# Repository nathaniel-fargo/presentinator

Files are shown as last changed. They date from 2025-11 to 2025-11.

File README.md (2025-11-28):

# the PRESENTINATOR

## Plot
Santa got a cold, and it's December 24th! As his top elf you gotta step it up\
You decide to make a cannon to launch presents from the North Pole all over the world.\
Each house will light up when it's clock strikes midnight and you must shoot your target to the correct one.\
The longer you hold the trigger, the further your present will be shot. You call it, "the PRESENTINATOR".\
(Depending on how well this goes, you might be in for a raise aftewards... and boy do you love Candy Canes)

## Project
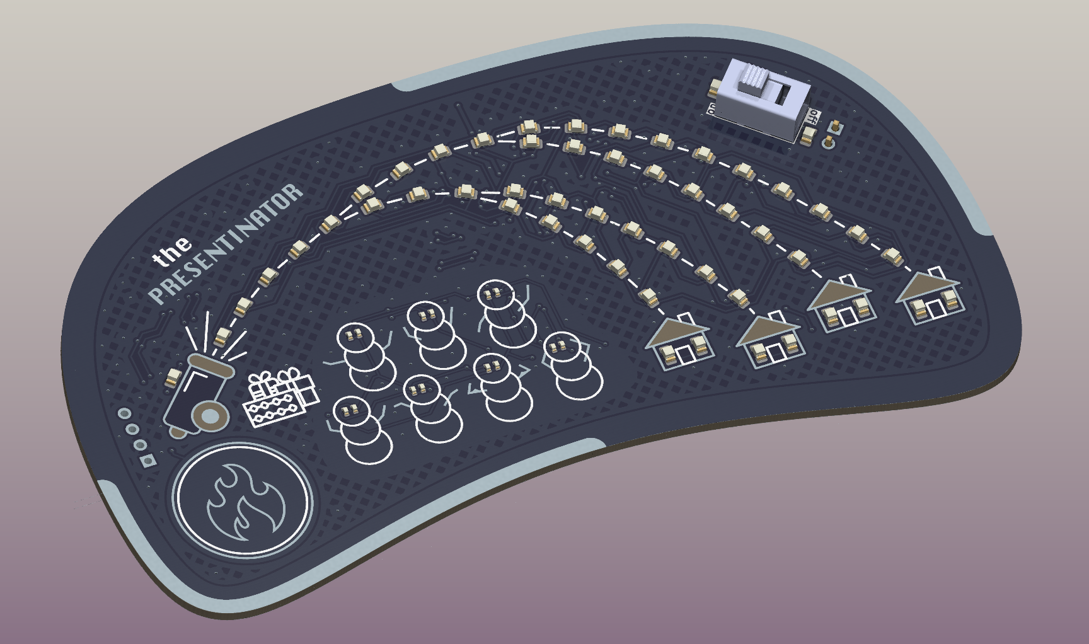
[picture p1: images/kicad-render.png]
KiCad PCB Render

There's hardware, graphics, and soon to be firmware in this repo.\
I initially designed this as a four layer board, but when I experimenting with deleting the inner layers, practically all the grounds were routed together besides a few floating islands. Everything should be low speed enough so that's fine.\
The project is powered off of two 2032s, with a switch, and then minimal polarity protection and then bucked down to 3.3V.\
The brains of the operation is the STM32F030F4, a very minimal STM microcontroller.\
Over I2C it drives the IS31FL3731-SA LED Matrix driver, which is not used to full capacity.\
There's also a capactive sense button IC, as well as the capability to drive a vibration motor for full haptic I/O.

## Status
Hardware: Designed\
Board: Being manufactured\
Firmware: Will be done by Christmas

## License
MIT Open Source License-inator

## Motivation
I have some younger people in my life and a habit of making DIY christmas presents. In the past they've been largely "crafty" (e.g. wood, leather) but this year I went all-in on electronics.

## Inspiration
Roughly inspired by the [light rail](https://github.com/nonik0/Light-Rail) PCB train track project, as well as Doofenshmirtz's naming conventions.

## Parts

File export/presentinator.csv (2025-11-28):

Reference | Qty | Value | Footprint | DK_PN | Stocked
BT1 | 1 | CR2032 | Aloe:BAT_BAT-HLD-003-SMT | 1908-CR2032-ND
BT2 | 1 | CR2032 | Aloe:BAT_BAT-HLD-003-SMT | 343-BAT-HLD-003-SMT-ND
C1,C2,C3,C4,C5,C6,C7 | 7 | 4u7 | Capacitor_SMD:C_0402_1005Metric_Pad0.74x0.62mm_HandSolder |  | y
CB1 | 1 | Touch Me | TestPoint:TestPoint_Pad_1.0x1.0mm |  | y
D25 | 1 | RB521S30T1G | Diode_SMD:D_SOD-523 |  | y
DB1 | 1 | LED | LED_SMD:LED_0805_2012Metric_InnerMarking | B1701NB--20D000114U1930
DB2 | 1 | LED | LED_SMD:LED_0805_2012Metric_InnerMarking | B1701URO-20D000114U1930
DC1,DH2,DH4,DH6,DH8 | 5 | LED_Small | LED_SMD:LED_0805_2012Metric_InnerMarking | B1701URO-20D000114U1930
DH1,DH3,DH5,DH7 | 4 | LED_Small | LED_SMD:LED_0805_2012Metric_InnerMarking | B1701NB--20D000114U1930
DP1,DP2,DP3,DP4,DP5,DP6,DP7,DP8,DP9,DP10,DP11,DP12,DP13,DP14,DP15,DP16,DP17,DP18,DP19,DP20,DP21,DP22,DP23,DP24,DP25,DP26,DP27,DP28,DP29,DP30,DP31,DP32,DP33,DP34,DP35,DP36,DP37,DP38,DP39,DP40,DP41,DP42 | 42 | LED_Small | LED_SMD:LED_0805_2012Metric_InnerMarking | B1701UY--20D000214U1930
DS1,DS2,DS3,DS4,DS5,DS6,DS7,DS8,DS9,DS10,DS11,DS12,DS13,DS14 | 14 | LED_Small | LED_SMD:LED_0402_1005Metric_Minimal | EAST10052WA0
J1 | 1 | SWD | Connector_PinHeader_2.54mm:PinHeader_1x04_P2.54mm_Vertical |  | y
L1 | 1 | MAMK2520T4R7M | Inductor_SMD:L_1008_2520Metric_Pad1.43x2.20mm_HandSolder | MAMK2520T4R7M
M1 | 1 | Motor_DC | Connector_PinHeader_2.54mm:PinHeader_1x02_P2.54mm_Vertical | 1188-VIBRATING-MOTOR-ND
Q1 | 1 | PJA3401A | Package_TO_SOT_SMD:SOT-23-3 | PJA3401A_R1_00001
Q2 | 1 | AO3400A | Package_TO_SOT_SMD:SOT-23-3 | AO3400A
R1 | 1 | 100 | Resistor_SMD:R_0402_1005Metric_Pad0.72x0.64mm_HandSolder |  | y
R2,R3,R10,R11,R12 | 5 | 10k | Resistor_SMD:R_0402_1005Metric_Pad0.72x0.64mm_HandSolder |  | y
R4 | 1 | 0 | Resistor_SMD:R_0402_1005Metric_Pad0.72x0.64mm_HandSolder |  | y
R5,R6 | 2 | 100k | Resistor_SMD:R_0402_1005Metric_Pad0.72x0.64mm_HandSolder |  | y
R7 | 1 | 20k | Resistor_SMD:R_0402_1005Metric_Pad0.72x0.64mm_HandSolder |  | y
R8,R9 | 2 | 1k | Resistor_SMD:R_0402_1005Metric_Pad0.72x0.64mm_HandSolder |  | y
S1 | 1 | SLW-105558-2A-N-D | Aloe:SW_SLW-105558-2A-N-D | 2223-SLW-105558-2A-N-D-ND
U1 | 1 | STM32F030F4 | Package_SO:TSSOP-20_4.4x6.5mm_P0.65mm | STM32F030F4P6
U2 | 1 | MCP1603 | Package_TO_SOT_SMD:TSOT-23-5 | MCP1603T-330I/OS
U3 | 1 | IS31FL3731-SA | Package_SO:SSOP-28_5.3x10.2mm_P0.65mm | IS31FL3731-SALS2
U4 | 1 | CAP1203-1-SN | Aloe:SOIC127P600X175-8N | CAP1203-1-SN

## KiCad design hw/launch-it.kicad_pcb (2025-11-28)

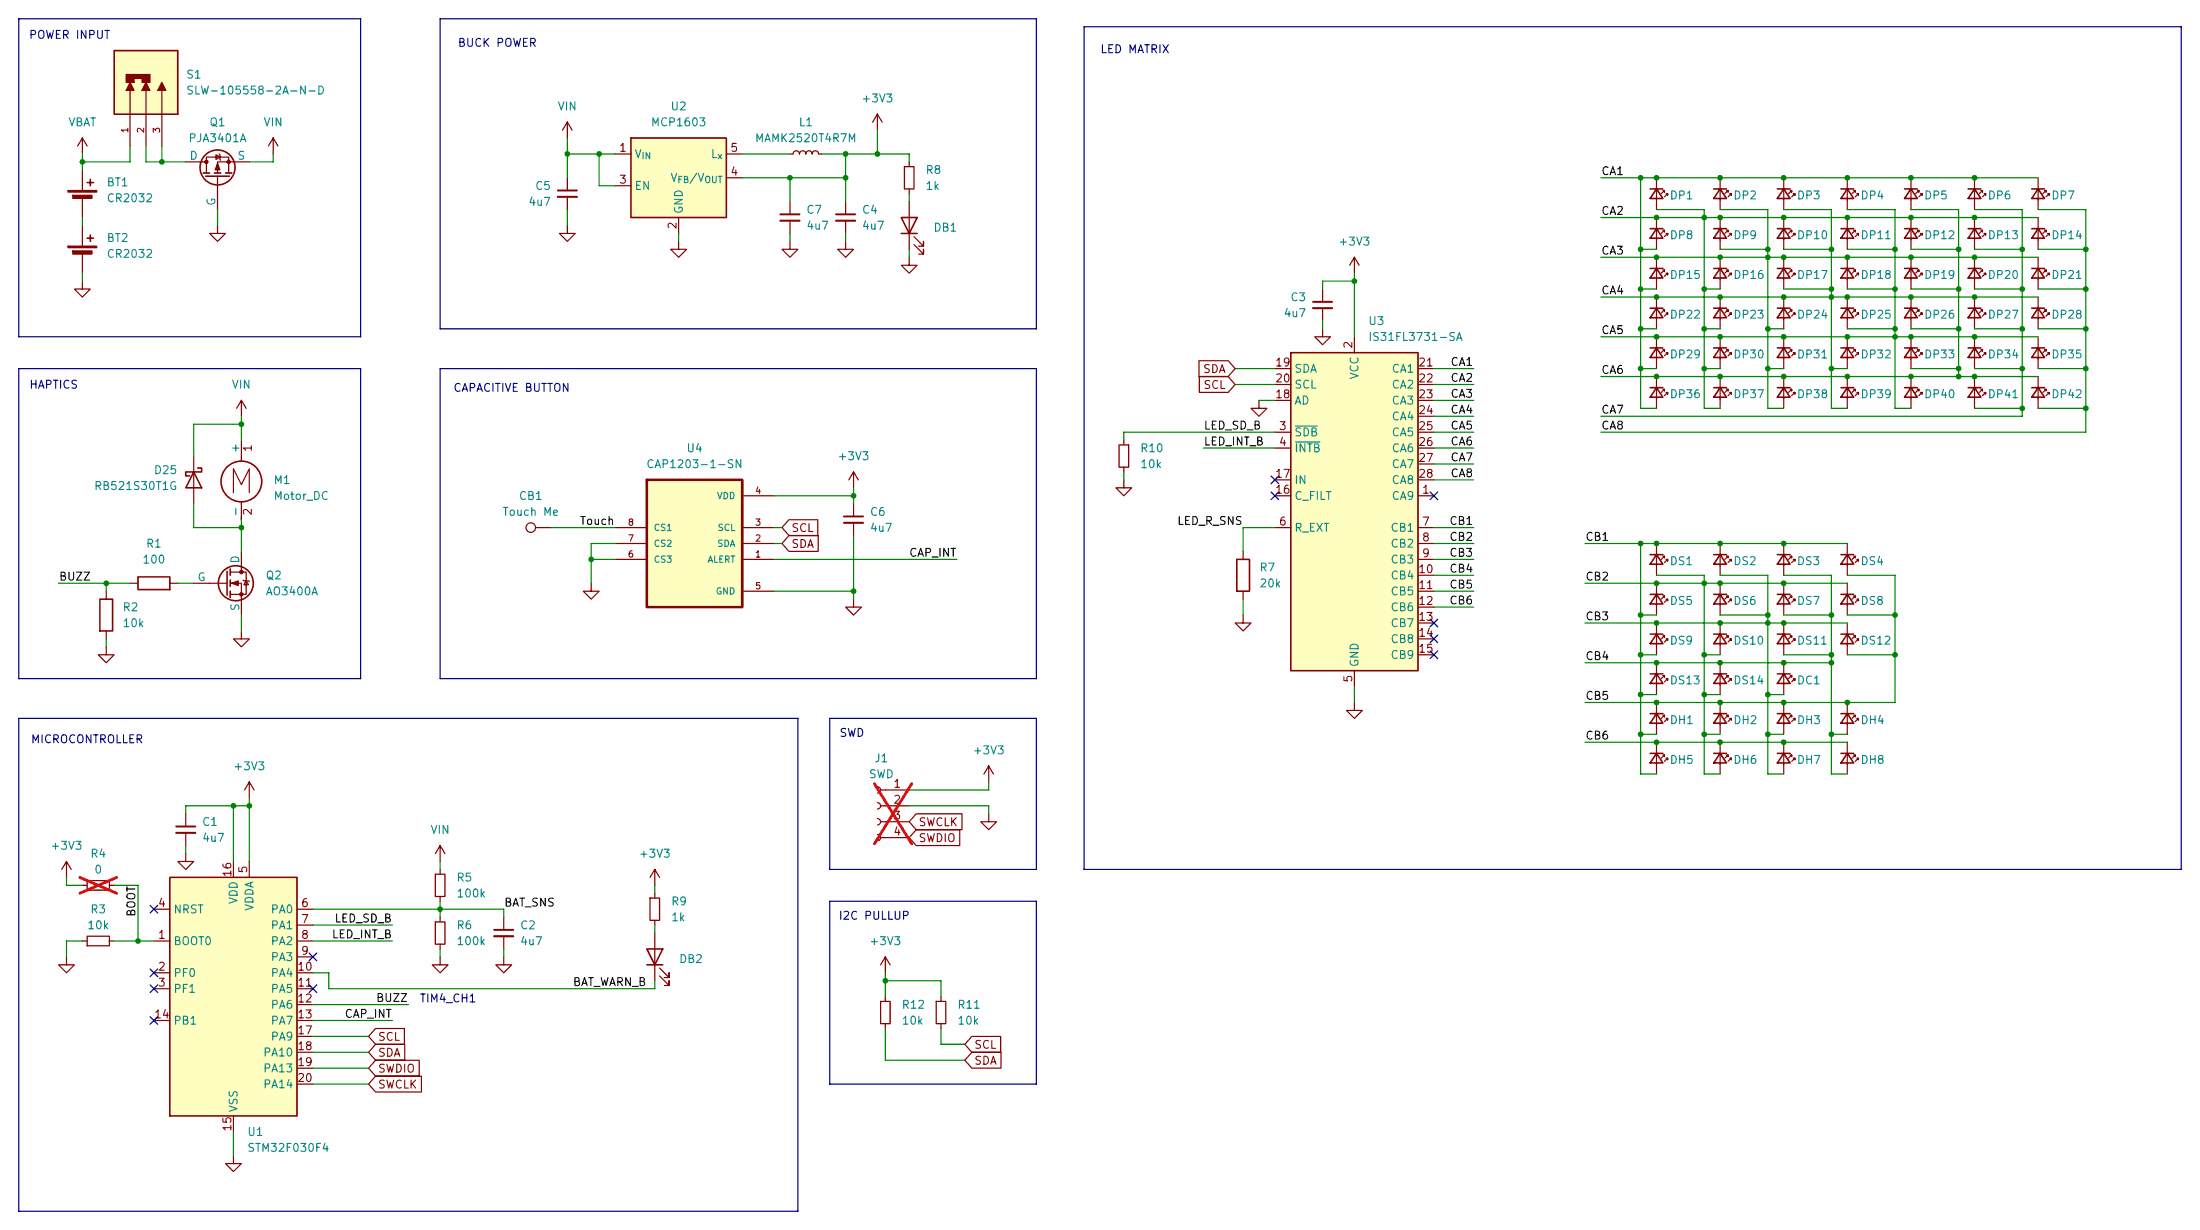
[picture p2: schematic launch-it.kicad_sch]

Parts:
BT1, BT2: CR2032; BAT_BAT-HLD-003-SMT
C1, C2, C3, C4, C5, C6, C7: 4u7; C_0402_1005Metric_Pad0.74x0.62mm_HandSolder
CB1: Touch Me; TestPoint_Pad_1.0x1.0mm
D25: RB521S30T1G; D_SOD-523
DB1, DB2: LED; LED_0805_2012Metric_InnerMarking
DC1: LED_Small; LED_0805_2012Metric_InnerMarking
DH1, DH2, DH3, DH4, DH5, DH6, DH7, DH8: LED_Small; LED_0805_2012Metric_InnerMarking
DP1, DP2, DP3, DP4, DP5, DP6, DP7, DP8, DP9, DP10, DP11, DP12, DP13, DP14, DP15, DP16, DP17, DP18, DP19, DP20, DP21, DP22, DP23, DP24, DP25, DP26, DP27, DP28, DP29, DP30, DP31, DP32, DP33, DP34, DP35, DP36, DP37, DP38, DP39, DP40, DP41, DP42: LED_Small; LED_0805_2012Metric_InnerMarking
DS1, DS2, DS3, DS4, DS5, DS6, DS7, DS8, DS9, DS10, DS11, DS12, DS13, DS14: LED_Small; LED_0402_1005Metric_Minimal
J1: SWD; PinHeader_1x04_P2.54mm_Vertical; not fitted
L1: MAMK2520T4R7M; L_1008_2520Metric_Pad1.43x2.20mm_HandSolder
M1: Motor_DC; PinHeader_1x02_P2.54mm_Vertical
Q1: PJA3401A; SOT-23-3
Q2: AO3400A; SOT-23-3
R1: 100; R_0402_1005Metric_Pad0.72x0.64mm_HandSolder
R2, R3, R10, R11, R12: 10k; R_0402_1005Metric_Pad0.72x0.64mm_HandSolder
R4: 0; R_0402_1005Metric_Pad0.72x0.64mm_HandSolder; not fitted
R5, R6: 100k; R_0402_1005Metric_Pad0.72x0.64mm_HandSolder
R7: 20k; R_0402_1005Metric_Pad0.72x0.64mm_HandSolder
R8, R9: 1k; R_0402_1005Metric_Pad0.72x0.64mm_HandSolder
S1: SLW-105558-2A-N-D; SW_SLW-105558-2A-N-D; PARTREV 1.01
U1: STM32F030F4; TSSOP-20_4.4x6.5mm_P0.65mm
U2: MCP1603; TSOT-23-5
U3: IS31FL3731-SA; SSOP-28_5.3x10.2mm_P0.65mm
U4: CAP1203-1-SN; SOIC127P600X175-8N

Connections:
+3V3: C1.1, C3.1, C4.1, C6.1, C7.1, J1.1, L1.2, R4.1, R8.1, R9.1, R11.1, R12.1, U1.5 (VDDA), U1.16 (VDD), U2.4 (V_{FB}/V_{OUT}), U3.2 (VCC), U4.4 (VDD)
/BAT_SNS: C2.1, R5.2, R6.1, U1.6 (PA0)
/BAT_WARN_B: DB2.1 (K), U1.10 (PA4)
/BOOT: R3.2, R4.2, U1.1 (BOOT0)
/BUZZ: R1.1, R2.1, U1.12 (PA6)
/CA1: DP1.1 (K), DP2.1 (K), DP3.1 (K), DP4.1 (K), DP5.1 (K), DP6.1 (K), DP7.1 (K), DP8.2 (A), DP15.2 (A), DP22.2 (A), DP29.2 (A), DP36.2 (A), U3.21 (CA1)
/CA2: DP1.2 (A), DP8.1 (K), DP9.1 (K), DP10.1 (K), DP11.1 (K), DP12.1 (K), DP13.1 (K), DP14.1 (K), DP16.2 (A), DP23.2 (A), DP30.2 (A), DP37.2 (A), U3.22 (CA2)
/CA3: DP2.2 (A), DP9.2 (A), DP15.1 (K), DP16.1 (K), DP17.1 (K), DP18.1 (K), DP19.1 (K), DP20.1 (K), DP21.1 (K), DP24.2 (A), DP31.2 (A), DP38.2 (A), U3.23 (CA3)
/CA4: DP3.2 (A), DP10.2 (A), DP17.2 (A), DP22.1 (K), DP23.1 (K), DP24.1 (K), DP25.1 (K), DP26.1 (K), DP27.1 (K), DP28.1 (K), DP32.2 (A), DP39.2 (A), U3.24 (CA4)
/CA5: DP4.2 (A), DP11.2 (A), DP18.2 (A), DP25.2 (A), DP29.1 (K), DP30.1 (K), DP31.1 (K), DP32.1 (K), DP33.1 (K), DP34.1 (K), DP35.1 (K), DP40.2 (A), U3.25 (CA5)
/CA6: DP5.2 (A), DP12.2 (A), DP19.2 (A), DP26.2 (A), DP33.2 (A), DP36.1 (K), DP37.1 (K), DP38.1 (K), DP39.1 (K), DP40.1 (K), DP41.1 (K), DP42.1 (K), U3.26 (CA6)
/CA7: DP6.2 (A), DP13.2 (A), DP20.2 (A), DP27.2 (A), DP34.2 (A), DP41.2 (A), U3.27 (CA7)
/CA8: DP7.2 (A), DP14.2 (A), DP21.2 (A), DP28.2 (A), DP35.2 (A), DP42.2 (A), U3.28 (CA8)
/CAP_INT: U1.13 (PA7), U4.1 (ALERT)
/CB1: DH1.2 (A), DH5.2 (A), DS1.1 (K), DS2.1 (K), DS3.1 (K), DS4.1 (K), DS5.2 (A), DS9.2 (A), DS13.2 (A), U3.7 (CB1)
/CB2: DH2.2 (A), DH6.2 (A), DS1.2 (A), DS5.1 (K), DS6.1 (K), DS7.1 (K), DS8.1 (K), DS10.2 (A), DS14.2 (A), U3.8 (CB2)
/CB3: DC1.2 (A), DH3.2 (A), DH7.2 (A), DS2.2 (A), DS6.2 (A), DS9.1 (K), DS10.1 (K), DS11.1 (K), DS12.1 (K), U3.9 (CB3)
/CB4: DC1.1 (K), DH4.2 (A), DH8.2 (A), DS3.2 (A), DS7.2 (A), DS11.2 (A), DS13.1 (K), DS14.1 (K), U3.10 (CB4)
/CB5: DH1.1 (K), DH2.1 (K), DH3.1 (K), DH4.1 (K), DS4.2 (A), DS8.2 (A), DS12.2 (A), U3.11 (CB5)
/CB6: DH5.1 (K), DH6.1 (K), DH7.1 (K), DH8.1 (K), U3.12 (CB6)
/LED_INT_B: U1.8 (PA2), U3.4 (~INTB)
/LED_R_SNS: R7.1, U3.6 (R_EXT)
/LED_SD_B: R10.1, U1.7 (PA1), U3.3 (~SDB)
/Touch: CB1.1, U4.8 (CS1)
GND: BT2.2 (-), C1.2, C2.2, C3.2, C4.2, C5.2, C6.2, C7.2, DB1.1 (K), J1.2, Q1.2 (G), Q2.3 (S), R2.2, R3.1, R6.2, R7.2, R10.2, U1.15 (VSS), U2.2 (GND), U3.5 (GND), U3.18 (AD), U4.5 (GND), U4.6 (CS3), U4.7 (CS2)
unnamed: BT1.2 (-), BT2.1 (+)
unnamed: D25.2 (A), M1.2 (-), Q2.1 (D)
unnamed: DB1.2 (A), R8.2
unnamed: DB2.2 (A), R9.2
unnamed: Q1.1 (D), S1.2, S1.3
unnamed: Q2.2 (G), R1.2
unnamed: L1.1, U2.5 (L_{x})
SCL: R11.2, U1.17 (PA9), U3.20 (SCL), U4.3 (SCL)
SDA: R12.2, U1.18 (PA10), U3.19 (SDA), U4.2 (SDA)
SWCLK: J1.3, U1.20 (PA14)
SWDIO: J1.4, U1.19 (PA13)
VBAT: BT1.1 (+), S1.1
VIN: C5.1, D25.1 (K), M1.1 (+), Q1.3 (S), R5.1, U2.1 (V_{IN}), U2.3 (EN)

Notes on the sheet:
POWER INPUT
HAPTICS
MICROCONTROLLER
I2C PULLUP
BUCK POWER
TIM4_CH1
LED MATRIX
SWD
CAPACITIVE BUTTON

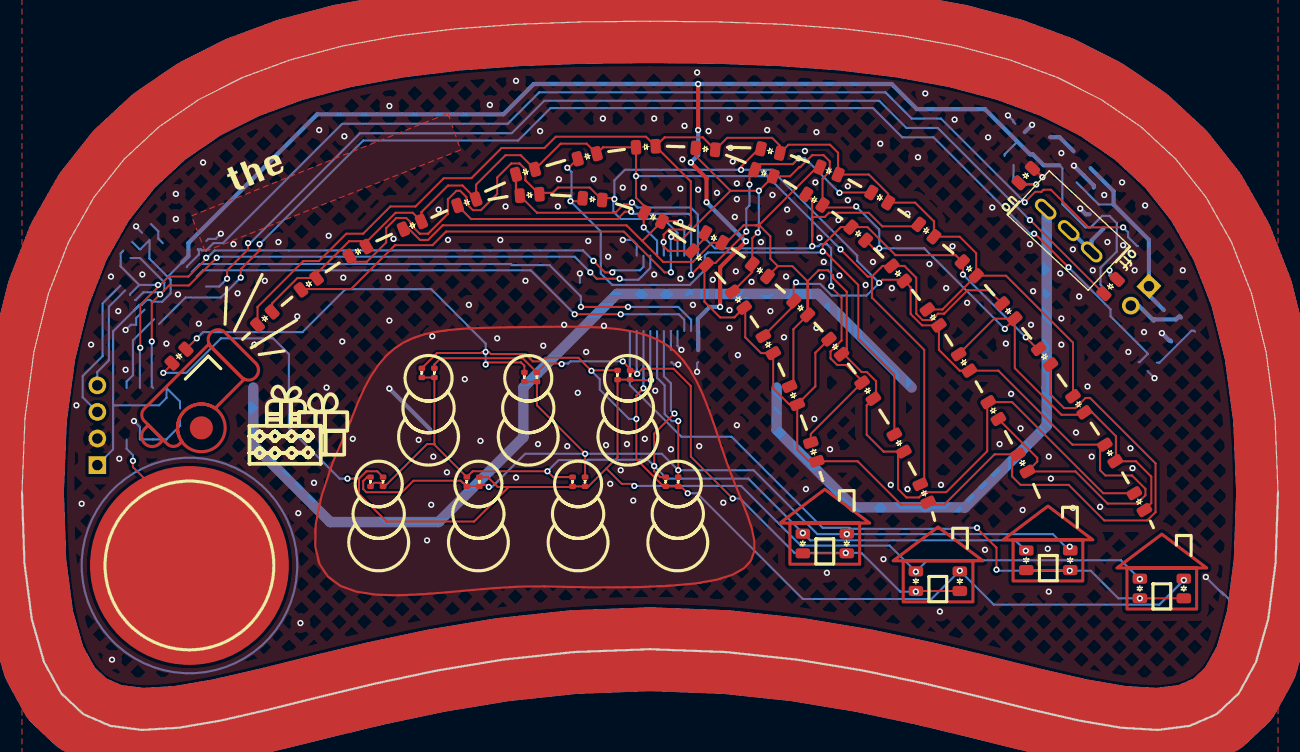
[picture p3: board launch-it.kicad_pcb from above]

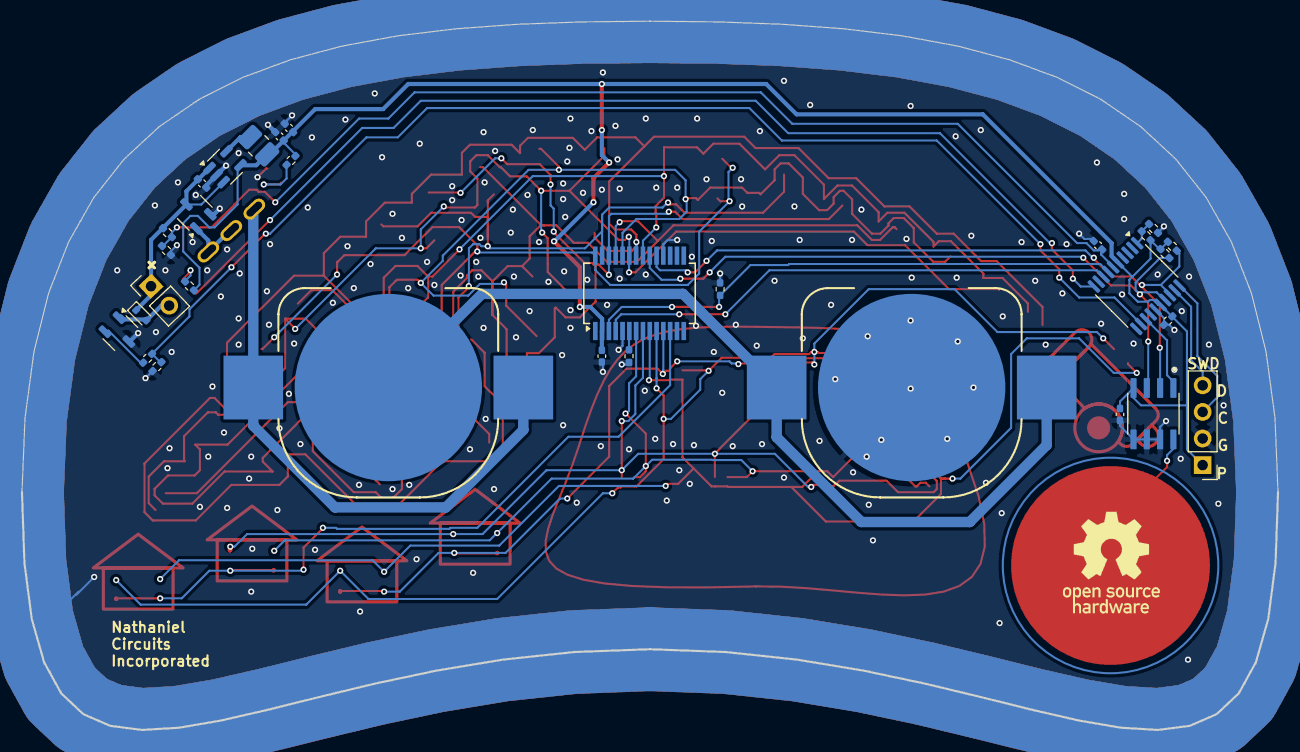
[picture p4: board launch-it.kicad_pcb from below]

Board: 2 copper layers, 120.0 x 67.7 mm, 100 parts (31 on the bottom side), 38 nets.

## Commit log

2025-11-28 updated CR2032 PN and minimal layout updates
    [launch-it.kicad_pcb, launch-it.kicad_sch, presentinator.csv]
2025-11-29 added updated gerber (maybe unnecessary, idk)
